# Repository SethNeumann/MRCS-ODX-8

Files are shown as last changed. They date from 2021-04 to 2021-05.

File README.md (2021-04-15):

# REPO NAME: MRCS-ODX-8
## License: Creative Commons Attribution-NonCommercial-ShareAlike

High Density Expandable cpOD-M motherboard.  Jon Robinson requested a larger motherboard
comparable to Dr. Chubb's ODMB. The requirement is to get as many cpOD-Ms as possible into a 7
x 15 CM board and provide connectors for expansion. Jon also requested keeping the logic 
level outputs away from the block power outputs.  The board will be expandable via an end
connector.  More than two are not recommended as the copper is only good for about 5 Amps.

ODX-8 are backward compatible with current cpOD-Ms, but mechanically will not fit DCC-ODs.
No software changes are needed.

- Board size 2.7" x 5.8" (69x150 mm)

- DCC Bus connections are 5 mm screw terminal blocks or 0.156 connector for expansion

- power, Ground, and Detector output connections are on a 10-position .100 (2.54 mm) screw terminal block.

The ODX-8 provides an economical and convenient mounting for up to eight cpOD-M detectors 

The ODX-8 mounts in DIN-Rail 70mm snap track or with #4 screws

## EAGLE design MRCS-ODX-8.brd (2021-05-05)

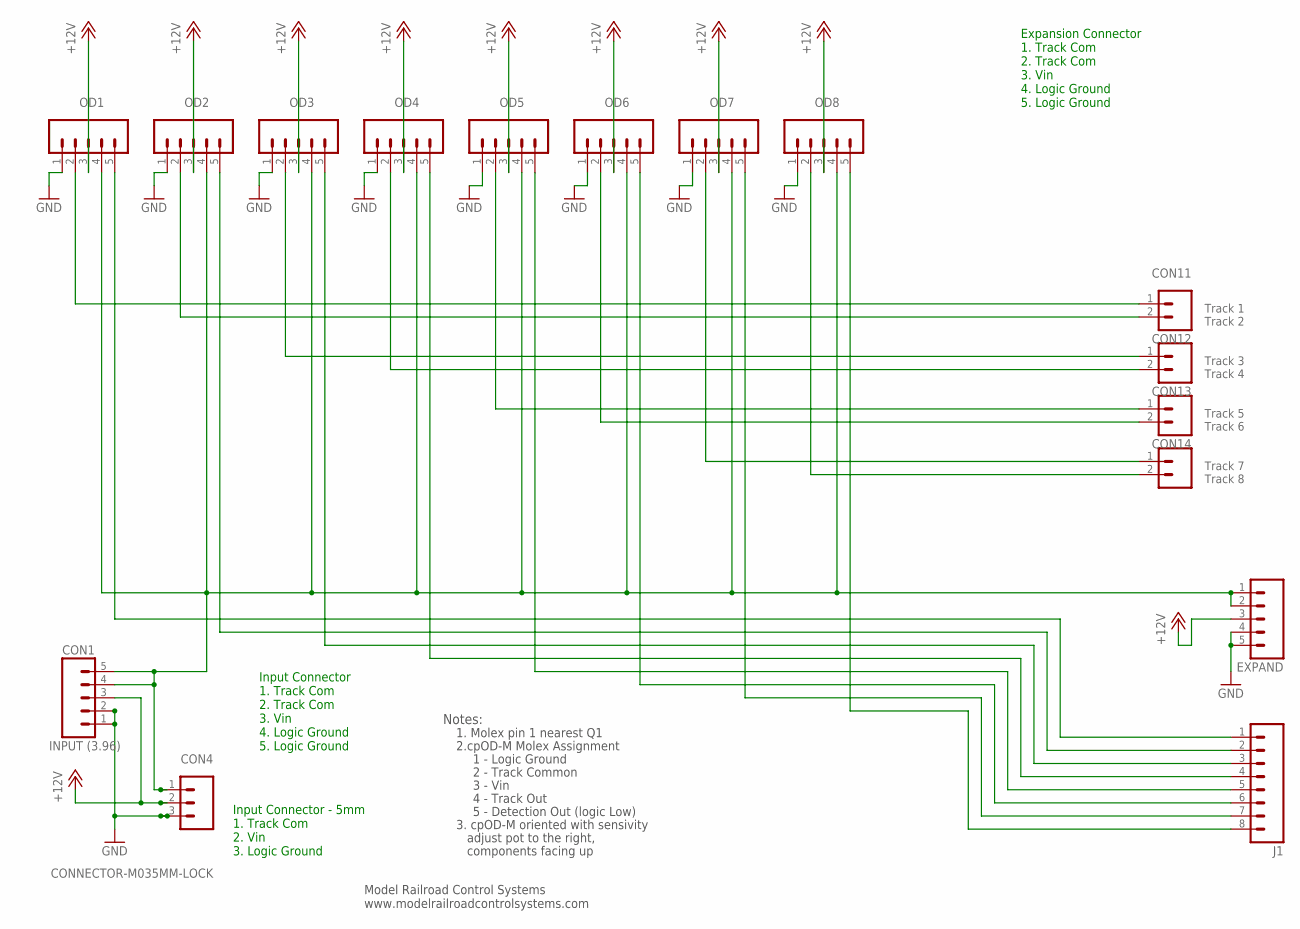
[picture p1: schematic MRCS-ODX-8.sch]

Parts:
CON1: INPUT (3.96); KK-156-5
CON4: CONNECTOR-M035MM-LOCK; SCREWTERMINAL-5MM-3
CON11, CON12, CON13, CON14: CONNECTOR-M025MM-LOCK; SCREWTERMINAL-5MM-2
EXPAND: CONNECTOR-M051.56; KK-156-5
J1: CONNECTOR-M08LOCK; 1X08_LOCK
OD1, OD2, OD3, OD4, OD5, OD6, OD7, OD8: CONNECTOR-M051.56; KK-156-5

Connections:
+12V: CON1.3, CON4.2, EXPAND.3, OD1.3, OD2.3, OD3.3, OD4.3, OD5.3, OD6.3, OD7.3, OD8.3
GND: CON1.1, CON1.2, CON4.3, EXPAND.4, EXPAND.5, OD1.1, OD2.1, OD3.1, OD4.1, OD5.1, OD6.1, OD7.1, OD8.1
unnamed: CON14.2 (B), OD8.2
unnamed: CON11.1 (A), OD1.2
unnamed: CON13.2 (B), OD6.2
unnamed: CON13.1 (A), OD5.2
unnamed: J1.2, OD2.5
unnamed: J1.1, OD1.5
unnamed: J1.4, OD4.5
unnamed: J1.5, OD5.5
unnamed: J1.6, OD6.5
unnamed: J1.8, OD8.5
unnamed: J1.7, OD7.5
unnamed: J1.3, OD3.5
unnamed: CON14.1 (A), OD7.2
unnamed: CON12.2 (B), OD4.2
unnamed: CON12.1 (A), OD3.2
unnamed: CON11.2 (B), OD2.2
TRACK_POWER: CON1.4, CON1.5, CON4.1, EXPAND.1, EXPAND.2, OD1.4, OD2.4, OD3.4, OD4.4, OD5.4, OD6.4, OD7.4, OD8.4

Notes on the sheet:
1 - Logic Ground
4 - Track Out
3 - Vin
2 - Track Common
5 - Detection Out (logic Low)
2.cpOD-M Molex Assignment
Notes:
3. cpOD-M oriented with sensivity
adjust pot to the right,
components facing up
Track 1 Track 2
Model Railroad Control Systems www.modelrailroadcontrolsystems.com
1. Molex pin 1 nearest Q1
Input Connector 1. Track Com 2. Track Com 3. Vin 4. Logic Ground 5. Logic Ground
Input Connector - 5mm 1. Track Com 2. Vin 3. Logic Ground
Track 3 Track 4
Track 5 Track 6
Track 7 Track 8
Expansion Connector 1. Track Com 2. Track Com 3. Vin 4. Logic Ground 5. Logic Ground

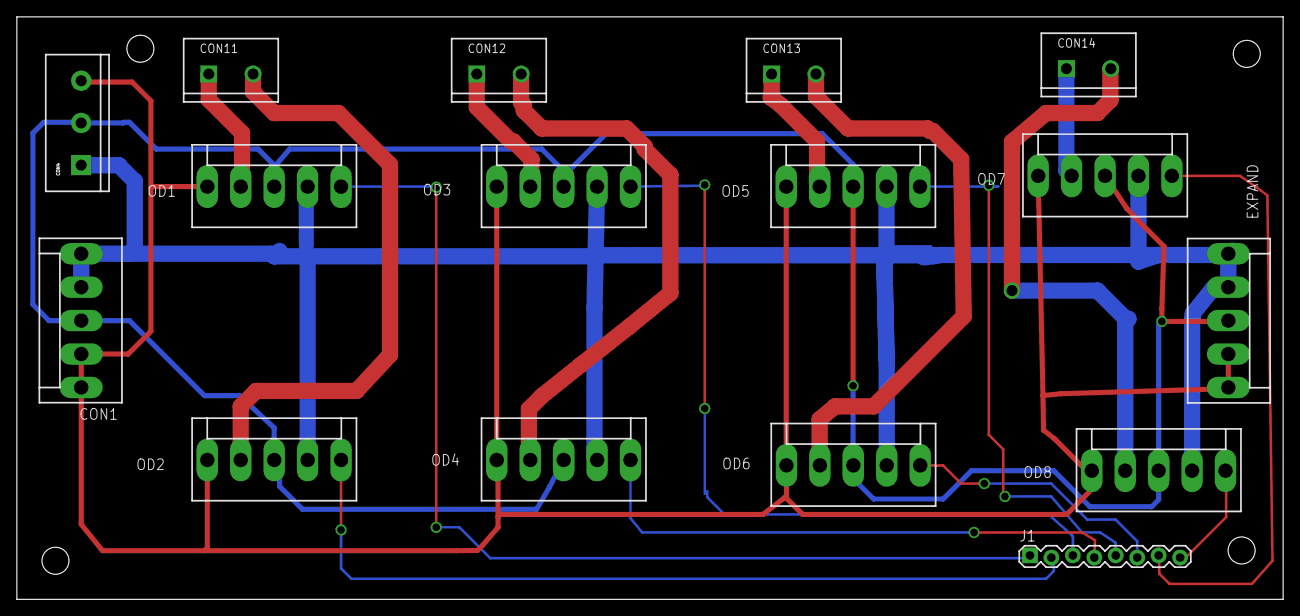
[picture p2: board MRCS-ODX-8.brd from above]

Board: 2 copper layers, 150.0 x 69.0 mm, 19 parts (0 on the bottom side), 19 nets.

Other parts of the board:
U$1: MRCSLOGOTOP
U$2: MRCSLOGOBTM
U$3: CA-PROP65WARNING

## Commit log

2021-04-04 copied ODX4 files in to start
    Would have forked but I couldn't figure out how to change the name while forking.
    [EagleTemplate-new.brd, EagleTemplate-new.sch, MRCS-ODX-8.brd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]
2021-04-15 Release Zero 20210405
    prototypes. Silkscreen on 3 position screw terminal has Track Common and GND reversed, needs adjustment of OD7 and expand needs to be moved inwards. Otherwise electrically OK. Track common bus on bottom can be cleaned up.
    [MRCS-ODX-8.brd, MRCS-ODX-8.csv, MRCS-ODX-8.sch]
2021-04-15 Revised after prototypes receieved
    cleaned up speculative language as it has been built
2021-04-15 changes after prototypes received
    changed to "fabricated"
2021-04-15 Received prototypes
    minor changes in languages to indicate it has been built and tested.
2021-04-15 prototypes received
    minor changes to indicate the board exists
2021-04-19 Rev 1.1
    corrected Silk Screen error on input connector, moved OD7 connector to make more room. Cleaned up track common bus.
    [MRCS-ODX-8.brd]
2021-05-05 minor changes and new gerbers
    revised gerbers
    [MRCS-ODX-8.brd, MRCS-ODX-8.csv]
